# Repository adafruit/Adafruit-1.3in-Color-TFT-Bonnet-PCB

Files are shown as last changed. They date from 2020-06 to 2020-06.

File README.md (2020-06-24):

## Adafruit 1.3in Color TFT Bonnet for Raspberry Pi - 240x240 TFT + Joystick Add-on PCB

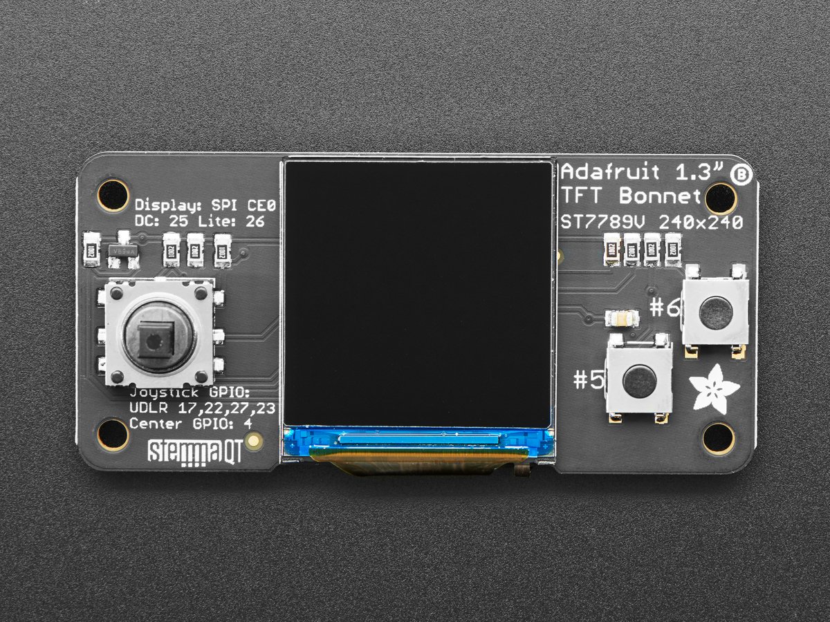
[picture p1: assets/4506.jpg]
<a href="http://www.adafruit.com/products/4506"><br/>
Click here to purchase one from the Adafruit shop</a>

PCB files for the Adafruit 1.3in Color TFT Bonnet for Raspberry Pi - 240x240 TFT + Joystick Add-on.

Format is EagleCAD schematic and board layout
* https://www.adafruit.com/product/4506

### Description

If you'd like a compact color display, with buttons and a joystick - we've got what you're looking for. The Adafruit 1.3" Color TFT Bonnet for Raspberry Pi is the big sister to our mini PiTFT add-ons. This bonnet has 240x240 color pixels in an IPS TFT display controlled over SPI. This display is super small, only about 1.3" diagonal, but since it is an IPS display, it's very readable with high contrast and visibility.

With the TFT display in the center, we had some space on either side so we added a 5-way joystick and two pushbuttons. Great for when you want to have a control interface for your project. On the bottom we have a Qwiic/STEMMA QT connector for I2C sensors and device so you can plug and play any of our STEMMA QT devices.

Using the display is very easy, we have a kernel driver and Python library for the ST7789 chipset. You can set it up as a console output so you can have text and user interface through the Raspberry Pi OS or you draw images, text, whatever you like, using the Python imaging library.  We also have Python code you can use to read the joystick and buttons. Our tests showed ~15 FPS update rates so you can do animations or simple video.

Comes completely pre-assembled and tested so you don't need to do anything but plug it in and install our Python code! Works with any Raspberry Pi computer, including the original Pi 1, B+, Pi 2, Pi 3, Pi 4, and Pi Zero.

### License

Adafruit invests time and resources providing this open source design, please support Adafruit and open-source hardware by purchasing products from [Adafruit](https://www.adafruit.com)!

Designed by Limor Fried/Ladyada for Adafruit Industries.

Creative Commons Attribution/Share-Alike, all text above must be included in any redistribution.
See license.txt for additional details.

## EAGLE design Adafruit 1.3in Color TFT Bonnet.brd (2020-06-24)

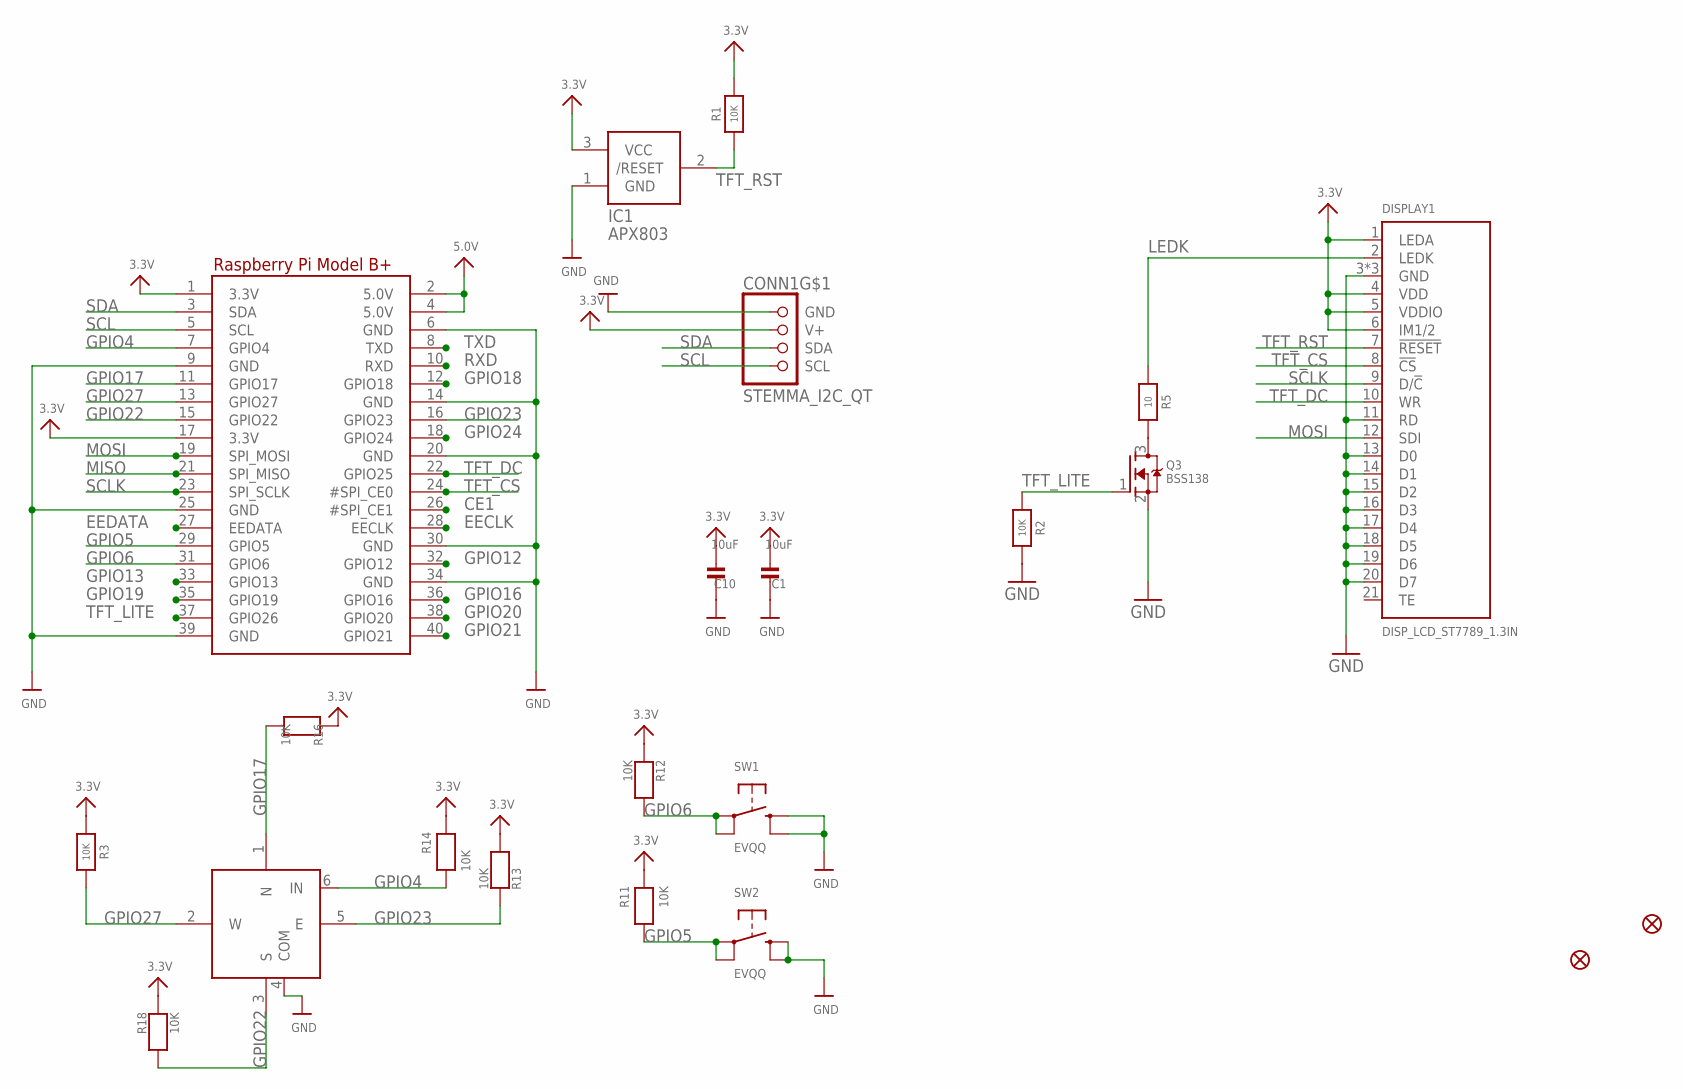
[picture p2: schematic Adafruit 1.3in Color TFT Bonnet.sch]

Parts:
C1, C10: 10uF; 0805-NO
CONN1: STEMMA_I2C_QT; JST_SH4
DISPLAY1: DISP_LCD_ST7789_1.3IN; TFT_1.3IN_240X240_24P
FID1, FID2: FIDUCIAL_1MM
IC1: APX803; SOT23
Q3: BSS138; SOT23-WIDE
R1, R3, R11, R12, R13, R14, R16, R18: 10K; 0805-NO
R2: 10K; 0603-NO
R5: 10; 0603-NO
RPI1: RASPBERRYPI_BPLUS_BONNETSMT; PI_BONNET_SMT
SW1: EVQQ; 6MMX6MM_TACTILE_SMT
SW2: EVQQ; 6MM_SMT
SW3: NAVSWITCHSKQUABAUE010; SKQUBAE010

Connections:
3.3V: C1.2, C10.2, CONN1.2 (V+), DISPLAY1.1 (LEDA), DISPLAY1.4 (VDD), DISPLAY1.5 (VDDIO), DISPLAY1.6 (IM1/2), IC1.3 (VCC), R1.2, R3.2, R11.2, R12.2, R13.2, R14.2, R16.1, R18.1, RPI1.1 (3.3V), RPI1.17 (3.3V)
5.0V: RPI1.2 (5.0V), RPI1.4 (5.0V)
CE1: RPI1.26 (#SPI_CE1)
EECLK: RPI1.28 (EECLK)
EEDATA: RPI1.27 (EEDATA)
GND: C1.1, C10.1, CONN1.1 (GND), DISPLAY1.3 (GND), DISPLAY1.11 (RD), DISPLAY1.13 (D0), DISPLAY1.14 (D1), DISPLAY1.15 (D2), DISPLAY1.16 (D3), DISPLAY1.17 (D4), DISPLAY1.18 (D5), DISPLAY1.19 (D6), DISPLAY1.20 (D7), DISPLAY1.23 (GND), DISPLAY1.24 (GND), IC1.1 (GND), Q3.2 (S), R2.1, RPI1.6 (GND), RPI1.9 (GND), RPI1.14 (GND), RPI1.20 (GND), RPI1.25 (GND), RPI1.30 (GND), RPI1.34 (GND), RPI1.39 (GND), SW1.B (S), SW1.B' (S1), SW2.B (S), SW2.B' (S1), SW3.4 (COM)
GPIO4: R14.1, RPI1.7 (GPIO4), SW3.6 (IN)
GPIO5: R11.1, RPI1.29 (GPIO5), SW2.A, SW2.A' (P1)
GPIO6: R12.1, RPI1.31 (GPIO6), SW1.A, SW1.A' (P1)
GPIO12: RPI1.32 (GPIO12)
GPIO13: RPI1.33 (GPIO13)
GPIO16: RPI1.36 (GPIO16)
GPIO17: R16.2, RPI1.11 (GPIO17), SW3.1 (N)
GPIO18: RPI1.12 (GPIO18)
GPIO19: RPI1.35 (GPIO19)
GPIO20: RPI1.38 (GPIO20)
GPIO21: RPI1.40 (GPIO21)
GPIO22: R18.2, RPI1.15 (GPIO22), SW3.3 (S)
GPIO23: R13.1, RPI1.16 (GPIO23), SW3.5 (E)
GPIO24: RPI1.18 (GPIO24)
GPIO27: R3.1, RPI1.13 (GPIO27), SW3.2 (W)
LEDK: DISPLAY1.2 (LEDK), R5.2
MISO: RPI1.21 (SPI_MISO)
MOSI: DISPLAY1.12 (SDI), RPI1.19 (SPI_MOSI)
unnamed: Q3.3 (D), R5.1
RXD: RPI1.10 (RXD)
SCL: CONN1.4 (SCL), RPI1.5 (SCL)
SCLK: DISPLAY1.9 (D/!C), RPI1.23 (SPI_SCLK)
SDA: CONN1.3 (SDA), RPI1.3 (SDA)
TFT_CS: DISPLAY1.8 (!CS), RPI1.24 (#SPI_CE0)
TFT_DC: DISPLAY1.10 (WR), RPI1.22 (GPIO25)
TFT_LITE: Q3.1 (G), R2.2, RPI1.37 (GPIO26)
TFT_RST: DISPLAY1.7 (!RESET), IC1.2 (/RESET), R1.1
TXD: RPI1.8 (TXD)

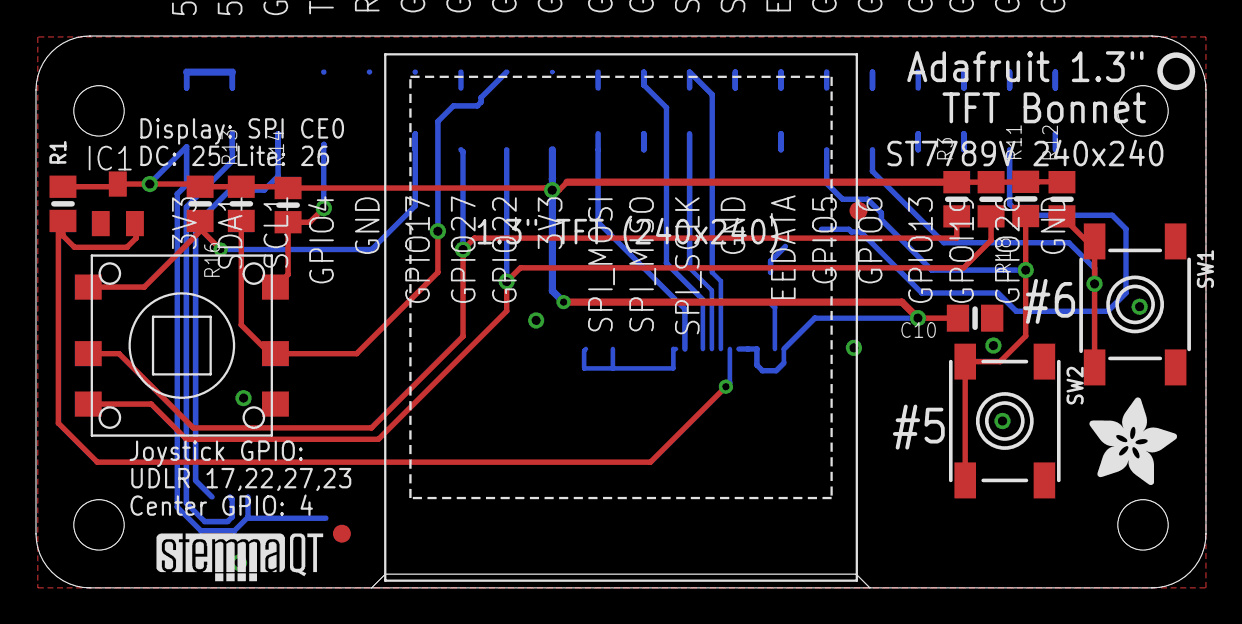
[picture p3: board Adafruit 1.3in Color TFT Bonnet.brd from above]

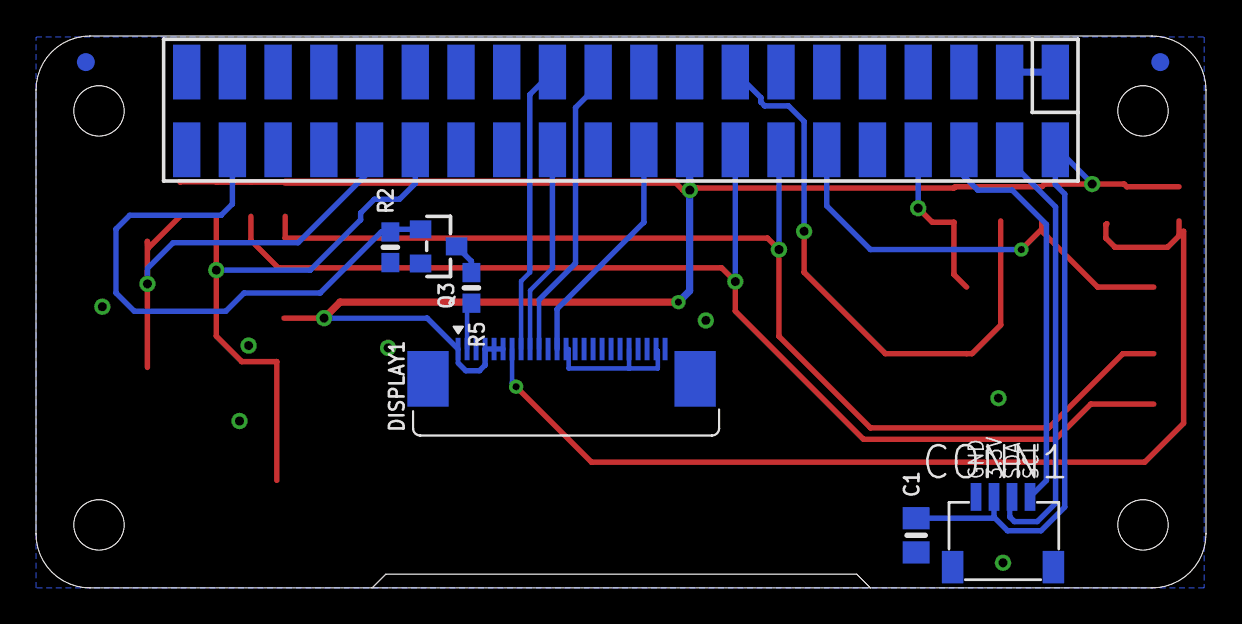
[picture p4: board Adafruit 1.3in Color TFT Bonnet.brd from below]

Board: 2 copper layers, 65.0 x 30.7 mm, 25 parts (6 on the bottom side), 20 nets.

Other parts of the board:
U$2: PCBFEAT-REV-040
U$28: ADAFRUIT_5MM
U$29: STEMMAQT
